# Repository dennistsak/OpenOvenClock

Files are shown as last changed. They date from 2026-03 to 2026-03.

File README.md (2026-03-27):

<p align="center">
  
</p>

# OpenOvenClock
An open-source oven timer project - and my first custom PCB design.

## Quick background
My oven's timer suddenly broke completely, producing an annoying loud noise whenever power was applied. After a teardown and some failed repair attempts on its badly worn PCB, it became clear that fixing it was not practical. Instead, I used this as an opportunity to design and manufacture my own PCB, adding some quality-of-life upgrades to the original timer design.

## Features & improvements
The new timer supports most of the original features including:
- 24-hour format time display.
- Time set screen with improved flow, in the form of button confirmation, instead of time based advance from hours to minutes.
- Countdown baking timer.

As well as several additions to the original design. More specifically:

- Rotary encoder with integrated switch. Supports single, double and long press inputs.
- Eco (night) mode. When enabled the display dims during the night.
- Configurable display brightness.
- Setting to disable optional buzzer sounds.
- Automatic locking after specific time.
- User friendly animations, that improve usability.
- Watchdog implementation in case of malfunction, defaulting in locked mode (disabled oven) after reset.
- Settings menu.
- Easily accessible reset button, with integrated hidden serial interface.

Some of this functionality can be seen below:

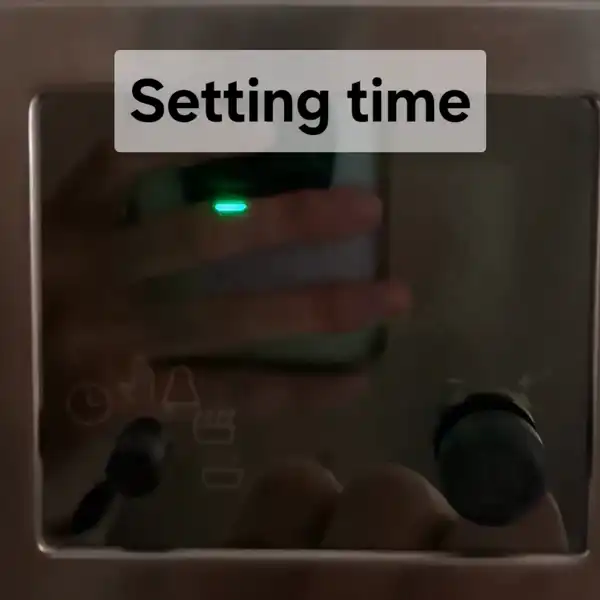
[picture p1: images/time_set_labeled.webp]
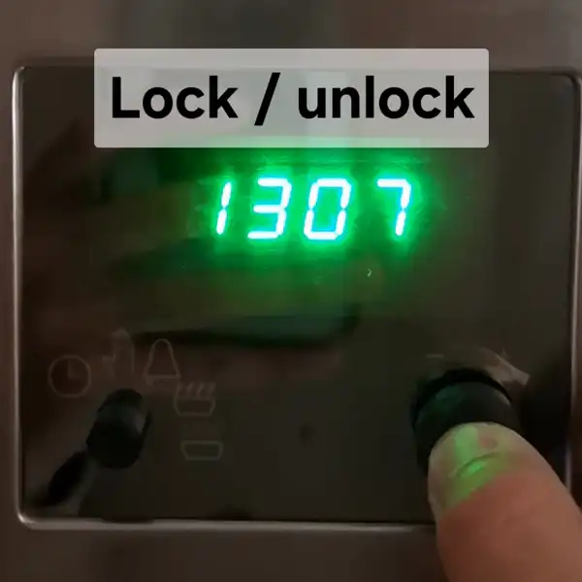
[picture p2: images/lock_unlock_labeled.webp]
|
:-------------------------------:|:-------------------------:
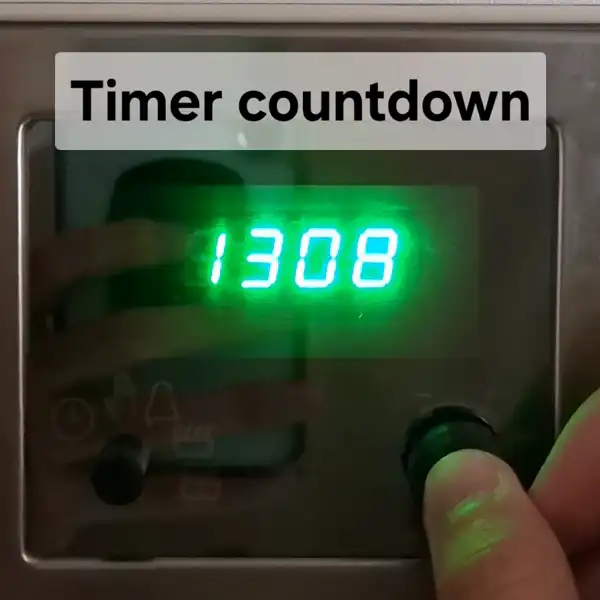
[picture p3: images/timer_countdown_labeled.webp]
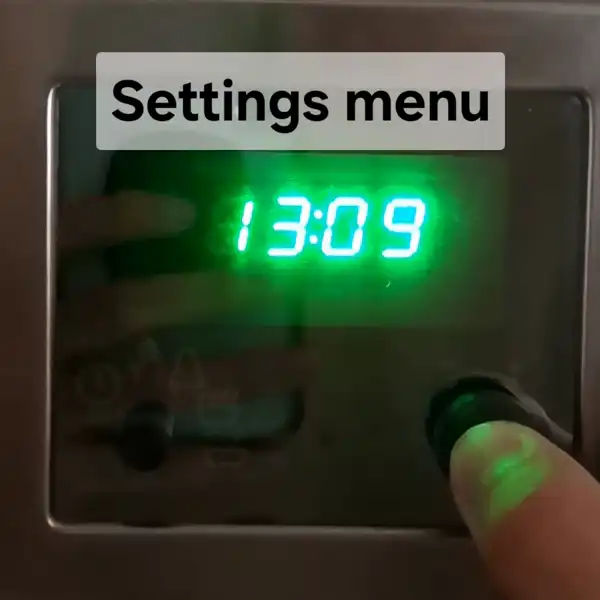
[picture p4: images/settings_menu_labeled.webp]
|

## Installation guide
In order to compile the firmware sketch for the ATmega328P, the Arduino IDE is required, as well as some 3rd party libraries.
### Libraries used:
- [LedControl](https://github.com/wayoda/LedControl) for communicating with the MAX7219.
- [DS3231](https://github.com/NorthernWidget/DS3231) for interfacing with the DS3231 RTC.
- [Switch](https://github.com/avdwebLibraries/avdweb_Switch) for rotary switch button de-bounce and multiple input type distinction.
- (Pre-installed) [Wire](https://docs.arduino.cc/language-reference/en/functions/communication/wire/) for I2C communication.
- (Pre-installed) [EEPROM](https://docs.arduino.cc/learn/built-in-libraries/eeprom/) for saving settings to the ATmega's EEPROM.
- (Pre-installed) [avr/wdt.h]() for implementing the watchdog timer.

After compiling the firmware sketch we need to flash it to the ATmega328P. For this guide we assume the use of the <b>FTDI FT232RL USB-to-Serial adapter</b>. In order for this adapter to function properly, it is required that the correct drivers are installed. This installation process is explained in great detail in this [guide](https://support.arduino.cc/hc/en-us/articles/4411305694610-Install-or-update-FTDI-drivers).

The final requirement for uploading the firmware, is an ATmega328P chip, that has a bootloader configured for using an external 16Mhz crystal, already burned. If such chip is unavailable, burning a bootloader is a relatively easy process by following the steps described in this [guide](https://support.arduino.cc/hc/en-us/articles/4841602539164-Burn-the-bootloader-on-UNO-Mega-and-classic-Nano-using-another-Arduino).

At this point, we are ready to proceed with the firmware flashing process. This process is described in the following steps:

1. Connect the USB-to-Serial adapter to the OpenOvenTimer board's serial port header.
2. Connect the USB-to-Serial adapter to an available USB port on the machine where Arduino IDE is installed.
3. Select the appropriate serial communication port inside Arduino IDE, when it appears.
4. Ensure the Serial Monitor window is closed, as it will in many cases interfere with the upload process.
5. Click the upload button and wait for the firmware flash process to complete.
6. Finally, click the reset button to get the micro-controller running on the new firmware.

## PCB design summary
During the PCB design process, several key challenges arose, the most important being the selection of devices that could reliably work together, to implement the desired functionality.

Some of the these choices are outlined below:

- When searching for a suitable micro-controller IC, the <b>ATmega328P-PN</b> variant was chosen, which provides slightly higher operating temperature margin, than the PU.
- For keeping track of time, the <b>DS3231 RTC</b> was selected. This IC provides more than adequate timekeeping functionality for this application, with an accuracy of ±3.5ppm until +85°C.
- A 4-digit 7-segment display is used, driven by a <b>MAX7219</b> IC. This display was selected as it was specifically made to support time format and the segments are green LEDs, that beautifully match the look of the original timer's VFD display.
- In order to include the auto baking functionality, a relay was added to switch the oven's loads (heaters, fan motors, etc). The selection process of an appropriate relay was tricky, as an oven consumes a lot of power. The original PCB used a relay that included quick-connect contacts. This eliminated the requirement for PCB traces that can handle large current.
<br>Taking these parameters into account, the <b>OMRON G4A-1A-E-DC5</b> relay was chosen. It provides a slightly higher contact current rating, while keeping the required coil voltage at 5V (instead of the original relay's 28V).
- For supplying power, a 5V PCB PSU module was selected, to save space and reduce complexity.

Board front side           |  Board back side
:-------------------------:|:-------------------------:
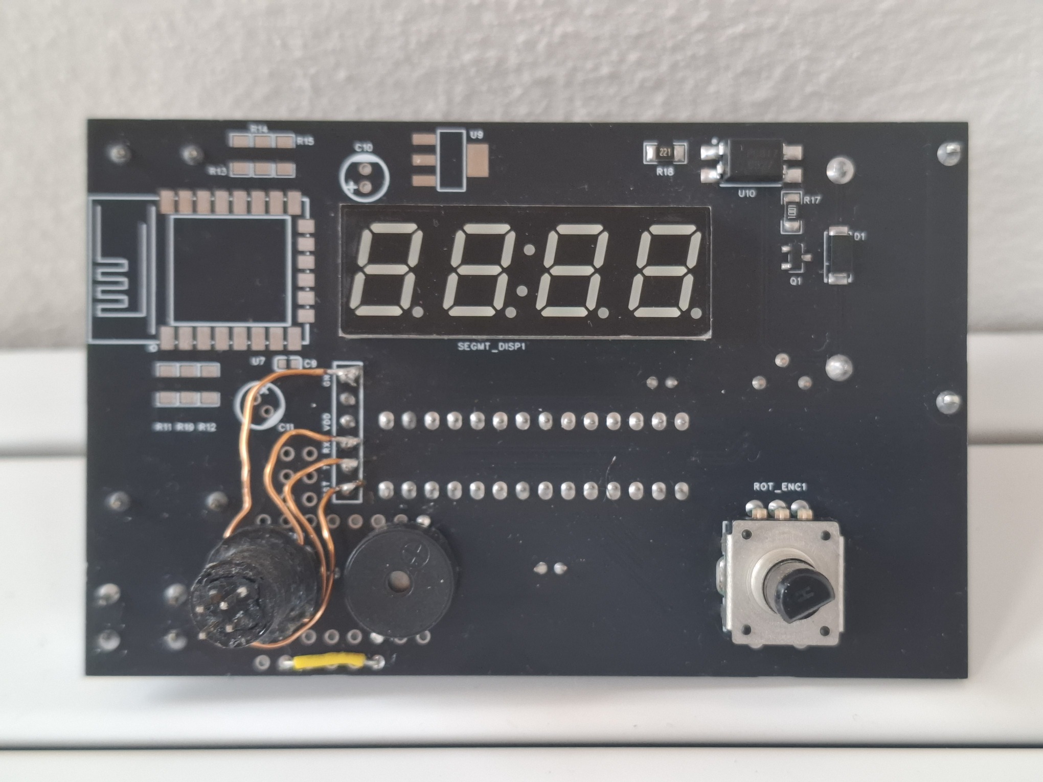
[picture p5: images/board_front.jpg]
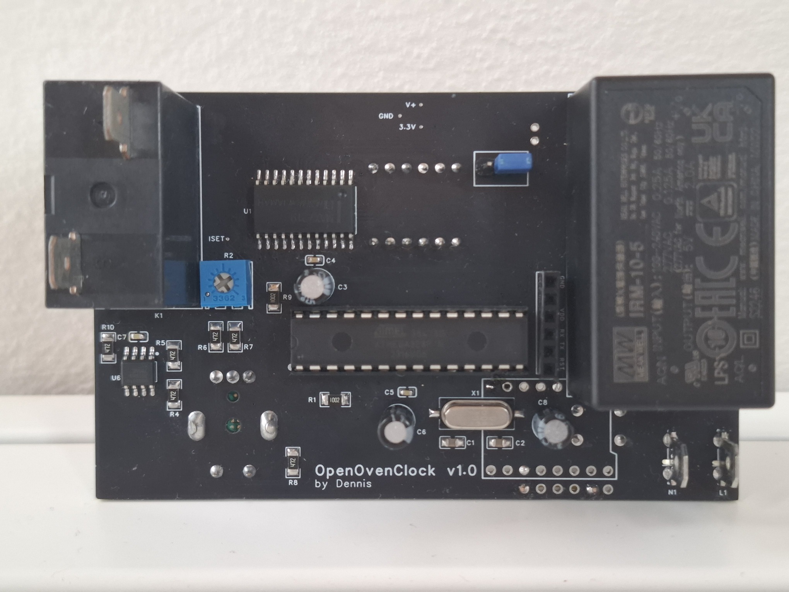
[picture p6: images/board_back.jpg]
|

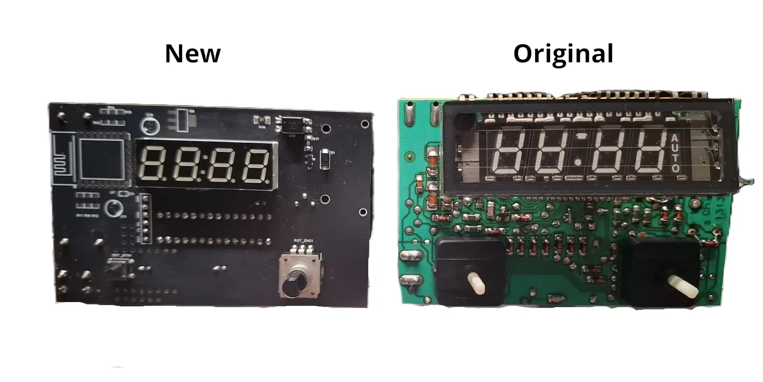
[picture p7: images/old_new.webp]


## Firmware design
While developing the firmware, a state machine architecture was used to ensure determinism.

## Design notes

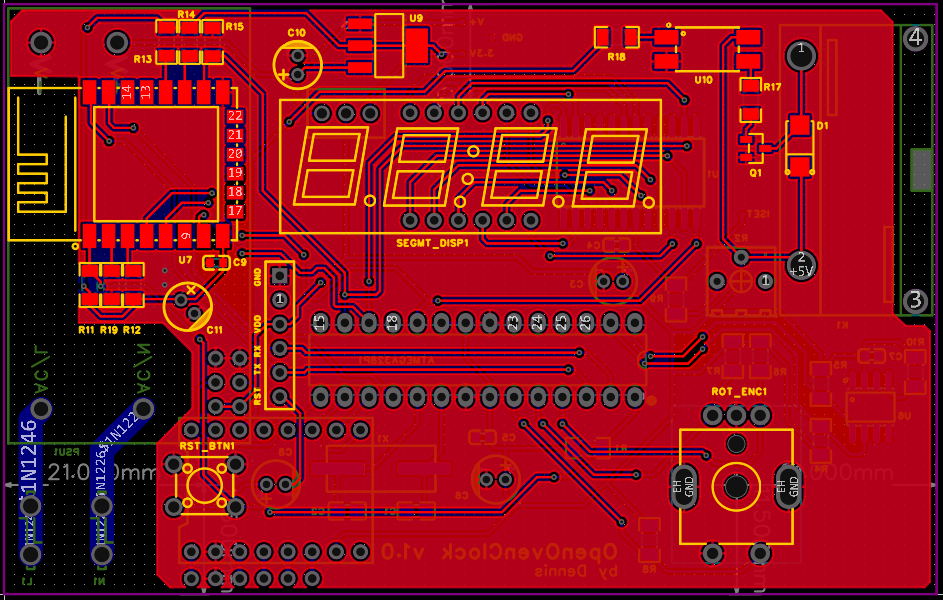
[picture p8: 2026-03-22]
images/pcb_eda.png

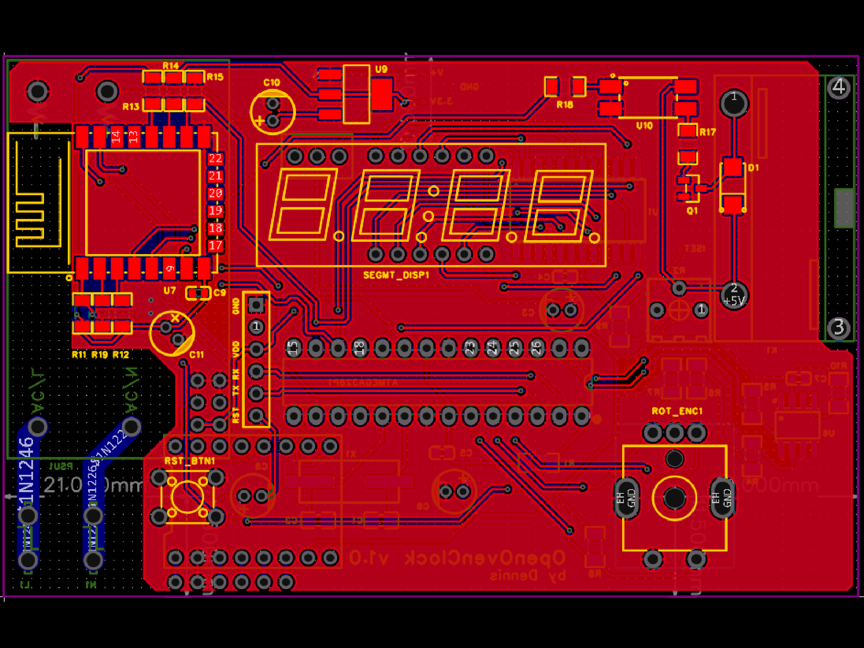
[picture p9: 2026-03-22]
images/pcb_eda_scaled.png

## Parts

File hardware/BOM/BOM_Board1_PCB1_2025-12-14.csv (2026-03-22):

No. | Quantity | Comment | Footprint | Value | Manufacturer Part | Manufacturer | Supplier Part | Supplier | Unique ID | LCSC Part Name | Designator
1 | 1 | 1kΩ | R1206 | 1kΩ | 1206W4F1001T5E | UNI-ROYAL(厚声) | C4410 | LCSC | gge25 | 1kΩ ±1% 250mW 厚膜电阻 | R17
2 | 1 | 2AS4T1A1M2RES | SW-TH_3P-P2.54_2AS4T1A1M2RES |  | 2AS4T1A1M2RES | HOOYA(皓宇电子) | C20611706 | LCSC | gge35 | 摇摆开关 | U12
3 | 1 | 2.4GHz | WIFIM-SMD_ESP-12F-ESP8266MOD | 2.4GHz | ESP-12F(ESP8266MOD) | Ai-Thinker(安信可) | C82891 | LCSC | gge21 | 完整的802.11b/g/nWi-FiSoC模块 屏蔽罩上的丝印是：ESP8266MOD，ESP8266EX串口WIFI | U7
4 | 1 | 16MHz | HC-49S_L11.4-W4.8 | 16MHz | X49SM16MSD2SC | YXC(扬兴晶振) | C12676 | LCSC | gge9 | HC-49SMD 16MHZ 2P 49SMD 20PF ±20PPM -20~70℃（±30PPM） | X1
5 | 1 | 50kΩ | RES-ADJ-TH_3362P | 50kΩ | 3362P-1-503 | JIERR(捷而瑞) | C48997904 | LCSC | gge14 | 3362P-1-503 | R2
6 | 1 | 220Ω | R1206 | 220Ω | 1206W4J0221T5E | UNI-ROYAL(厚声) | C25363 | LCSC | gge34 | 220Ω ±5% 250mW 厚膜电阻 | R18
7 | 1 | AMS1117-3.3 | SOT-223-3_L6.4-W3.5-P2.30-LS7.0-BR |  | AMS1117-3.3 | 国芯佳品 | C2992570 | LCSC | gge22 | 1A低压差线性稳压器 | U9
8 | 1 | ATMEGA328P-PN | PDIP-28_L35.0-W7.3-P2.54-LS7.8-BL |  | ATMEGA328P-PN | MICROCHIP(美国微芯) | C1337455 | LCSC | gge6 | 基于AVR增强型RISC架构的低功耗CMOS 8位微控制器 | ATMEGA328P1
9 | 1 | DS3231MZ+TRL | SOIC-8_L4.9-W3.9-P1.27-LS6.0-BL |  | DS3231MZ+TRL | ADI(亚德诺)/MAXIM(美信) | C107410 | LCSC | gge17 | 高精度RTC集成MEMS谐振器 | U6
10 | 1 | EC11G1560421 | SW-TH_EC11G1560421 |  | EC11G1560421 | ALPSALPINE(阿尔卑斯阿尔派) | C1322549 | LCSC | gge11 | 编码器 | ROT_ENC1
11 | 1 | G4A-1A-E DC12 | RELAY-TH_G4A-1A-E |  | G4A-1A-E DC12 | OMRON(欧姆龙) | C1563460 | LCSC | gge20 | 无锁存 | K1
12 | 1 | IRM-05-5 | PWRM-TH_IRM-05-5 |  | IRM-05-5 | null | C48603696 | LCSC | gge2 | MW(明纬) 单输出封装型PCB安装型胶囊型绿色模块开关电源 AC-DC 5W IRM-05-5 | PSU1
13 | 1 | M7 | SMA_L4.3-W2.6-LS5.2-RD |  | M7 | MDD(辰达半导体) | C95872 | LCSC | gge26 | 1kV 1A | D1
14 | 1 | MAX7219M/TR | SOP-24_L15.4-W7.5-P1.27-LS10.4-BL |  | MAX7219M/TR | HGSEMI(华冠) | C6705351 | LCSC | gge1 | MAX7219M/TR | U1
15 | 1 | PC817C | OPTO-SMD-4_L4.6-W6.5-P2.54-LS10.3-TL |  | PC817C | GOODWORK(固得沃克) | C3025164 | LCSC | gge24 | C档 光电晶体管光电耦合器 | U10
16 | 1 | SLR0394FG3C5BD-3.5 | LED-SEG-TH_SLR0394FG3C5BD-3.5 |  | SLR0394FG3C5BD-3.5 | SUNLIGHT(光华) | C225905 | LCSC | gge3 | 4位0.39英寸绿色数码管 共阴极 | SEGMT_DISP1
17 | 1 | SS8050(RANGE:200-350) | SOT-23-3_L2.9-W1.3-P1.90-LS2.4-BR |  | SS8050(RANGE:200-350) | CJ(江苏长电/长晶) | C2150 | LCSC | gge27 | hfe=200~350 NPN 电流:1.5A 电压:25V | Q1
18 | 1 | TS-1002-07026 | SW-TH_4P-L6.0-W6.0-P4.50-LS6.5 |  | TS-1002-07026 | XUNPU(讯普) | C455095 | LCSC | gge16 | 6*6*7mm 直插 轻触开关 | RST_BTN1
19 | 2 | 22pF | C0805 | 22pF | TCC0805COG220J500BT | CCTC(三环) | C376875 | LCSC | gge7,gge8 | 22pF ±5% 50V | C1,C2
20 | 2 | G630-09-3T | CONN-TH_2P-L8.2-W0.8-P5.10 |  | G630-09-3T | SAMZO(三佐) | C27636945 | LCSC | gge4,gge5 | 6.3mmPCB焊接端子-插片 | L1,N1
21 | 4 | 100nF | C0603 | 100nF | CL10B104KB8NNNC | SAMSUNG(三星) | C1591 | LCSC | gge12,gge12_1,gge12_2,gge12_3 | 100nF ±10% 50V | C3,C5,C7,C9
22 | 4 | Test-Point | Test-Point-0.5mm |  |  |  |  |  | gge28,gge29,gge30,gge33 |  | 3.3V,GND,ISET,V+
23 | 5 | 10uF | CAP-TH_BD5.0-P2.00-D0.8-FD | 10uF | 50YXJ10M5X11 | Rubycon(红宝石) | C432355 | LCSC | gge13,gge13_1,gge13_2,gge13_3,gge13_4 | 10uF ±20% 50V | C4,C6,C8,C10,C11
24 | 6 | 4.7kΩ | R1206 | 4.7kΩ | FRC1206J472 TS | FOJAN(富捷) | C2907499 | LCSC | gge18,gge18_1,gge18_2,gge18_3,gge19,gge19_1 | 4.7kΩ ±5% 250mW 厚膜电阻 | R4,R5,R6,R7,R8,R10
25 | 8 | 10kΩ | R1206 | 10kΩ | 1206W4F1002T5E | UNI-ROYAL(厚声) | C17902 | LCSC | gge10,gge10_1,gge10_2,gge10_3,gge10_4,gge10_5,gge10_6,gge10_7 | 10kΩ ±1% 250mW 厚膜电阻 | R1,R9,R11,R12,R13,R14,R15,R19

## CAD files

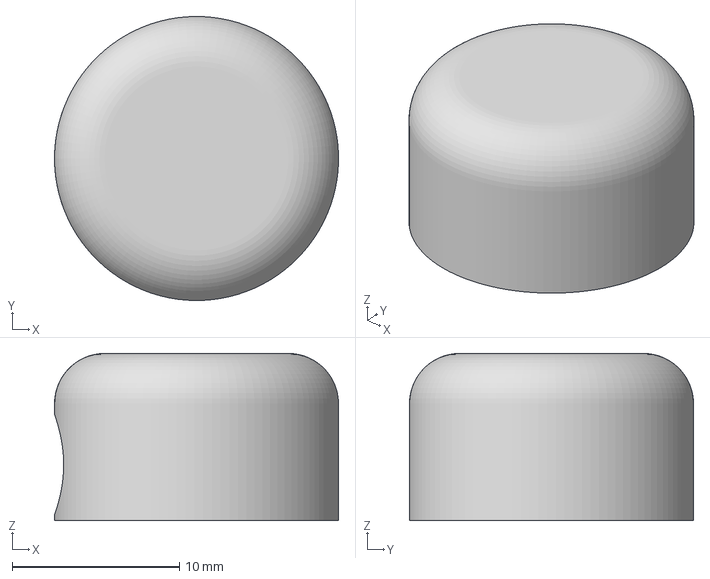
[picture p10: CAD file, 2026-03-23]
hardware/3D_models/knob_cap_v4.3mf
17.0 x 17.0 x 10.0 mm

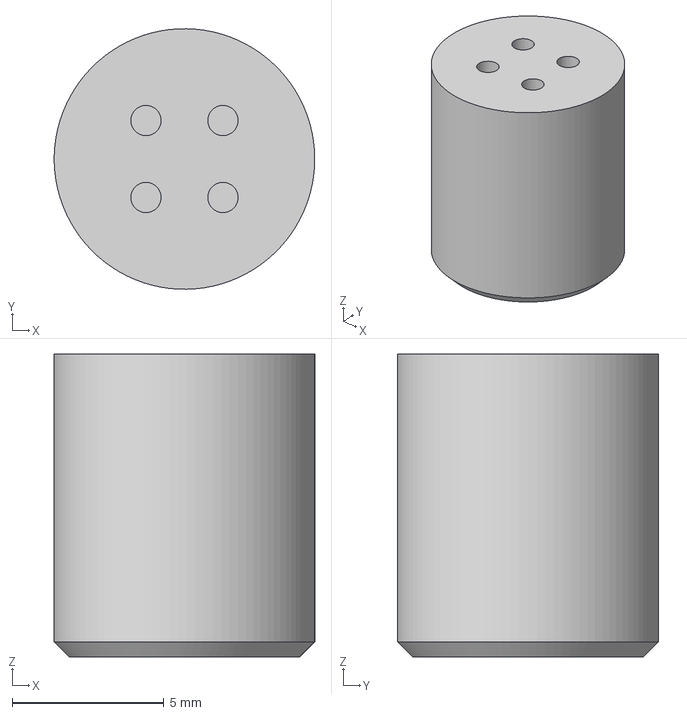
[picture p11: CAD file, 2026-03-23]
hardware/3D_models/rst_button_cap.3mf
8.60 x 8.60 x 10.0 mm

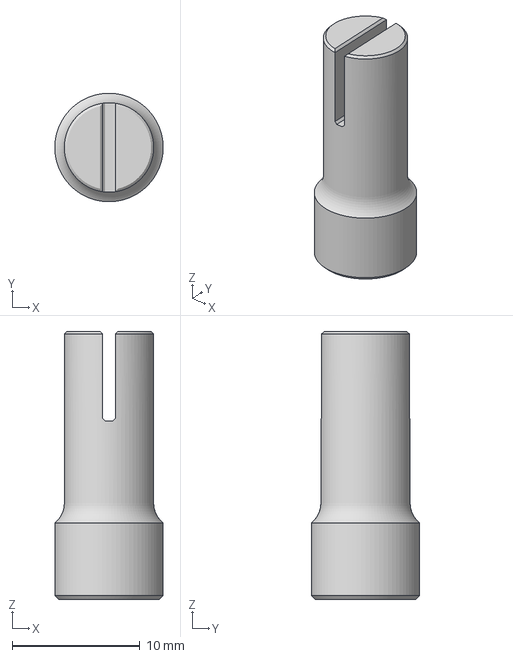
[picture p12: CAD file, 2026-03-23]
hardware/3D_models/knob_adapter_v4.3mf
8.50 x 8.49 x 21.0 mm

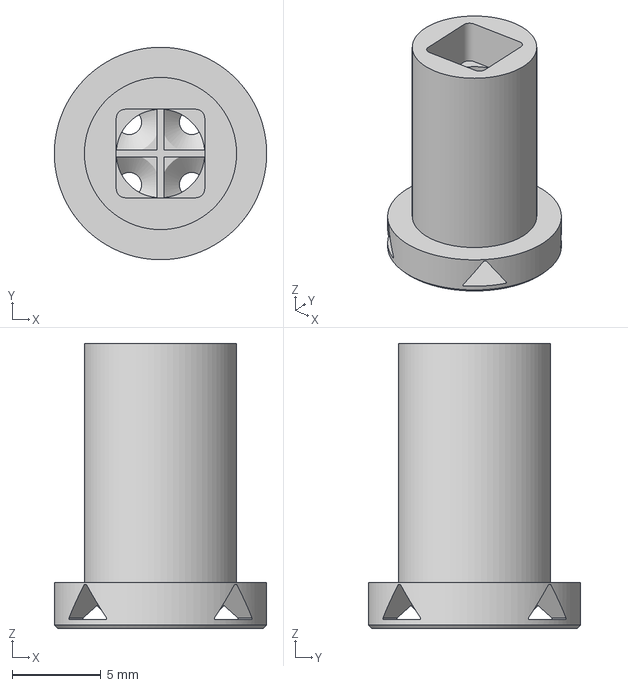
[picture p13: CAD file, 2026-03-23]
hardware/3D_models/rst_button.3mf
12.0 x 12.0 x 16.1 mm

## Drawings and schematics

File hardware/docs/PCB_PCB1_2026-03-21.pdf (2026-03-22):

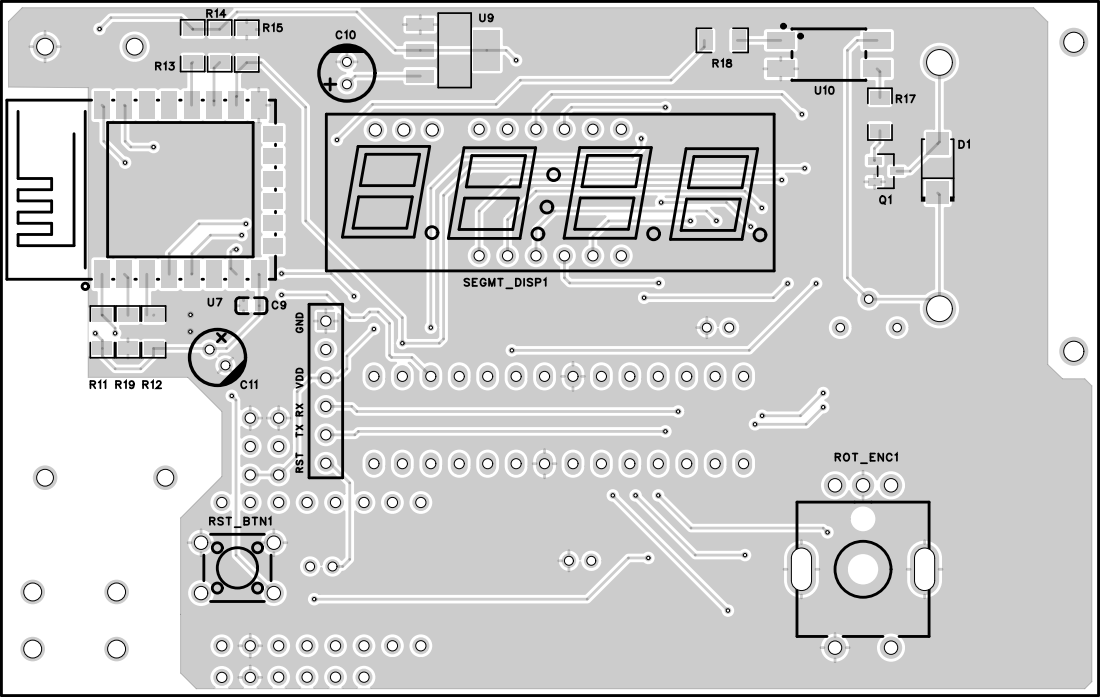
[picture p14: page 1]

RST TX RX VDD GND

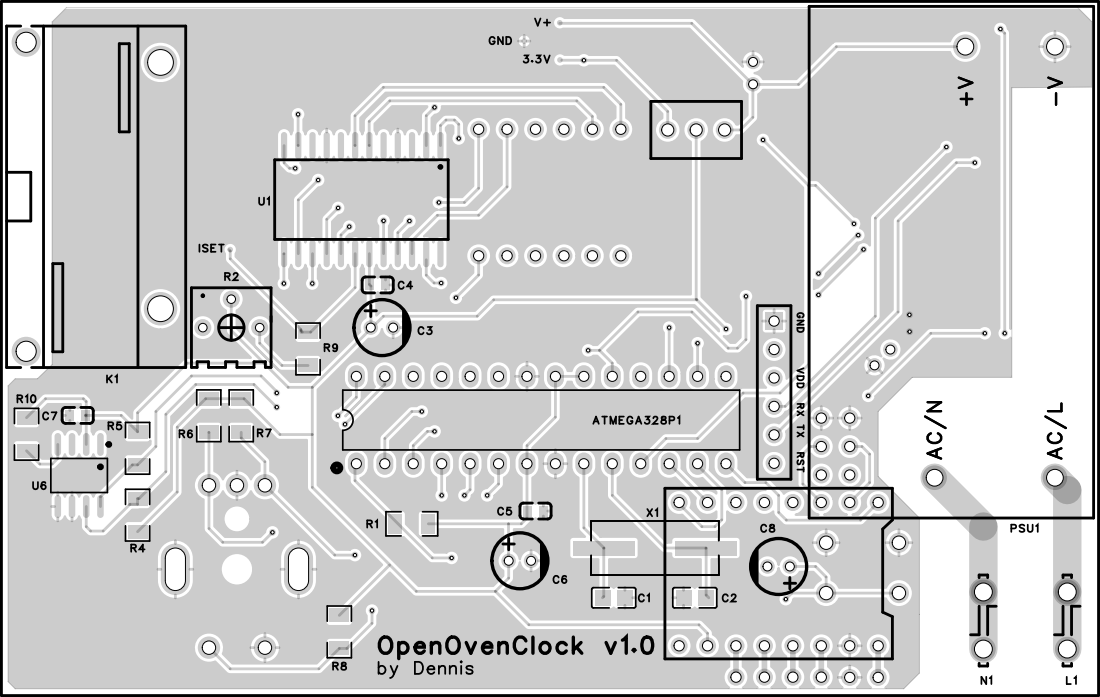
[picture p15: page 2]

GND VDD RX TX RST

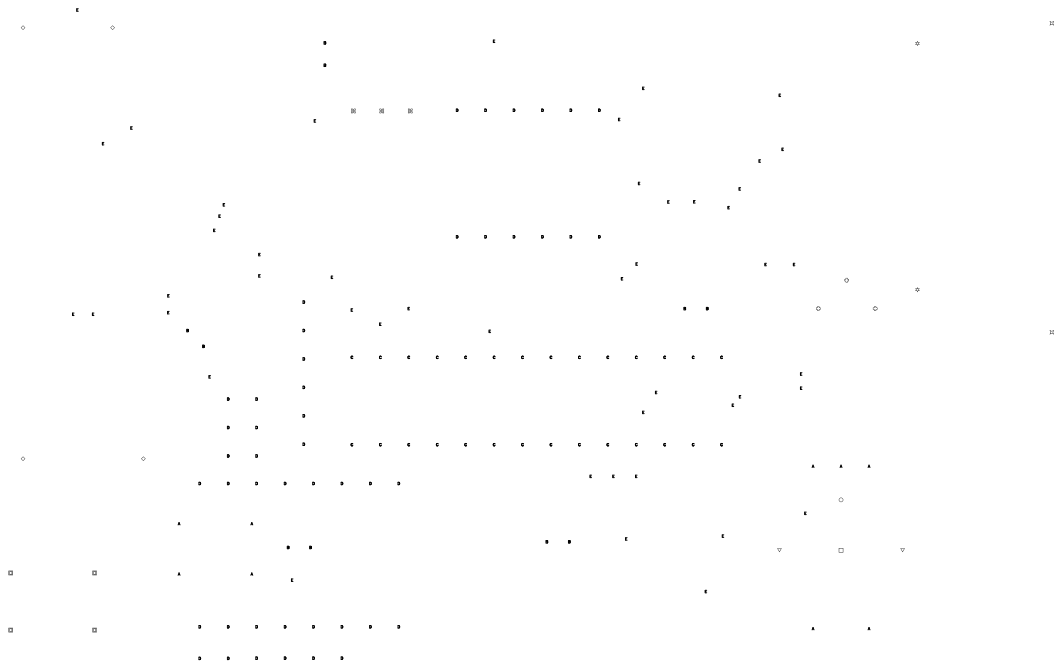
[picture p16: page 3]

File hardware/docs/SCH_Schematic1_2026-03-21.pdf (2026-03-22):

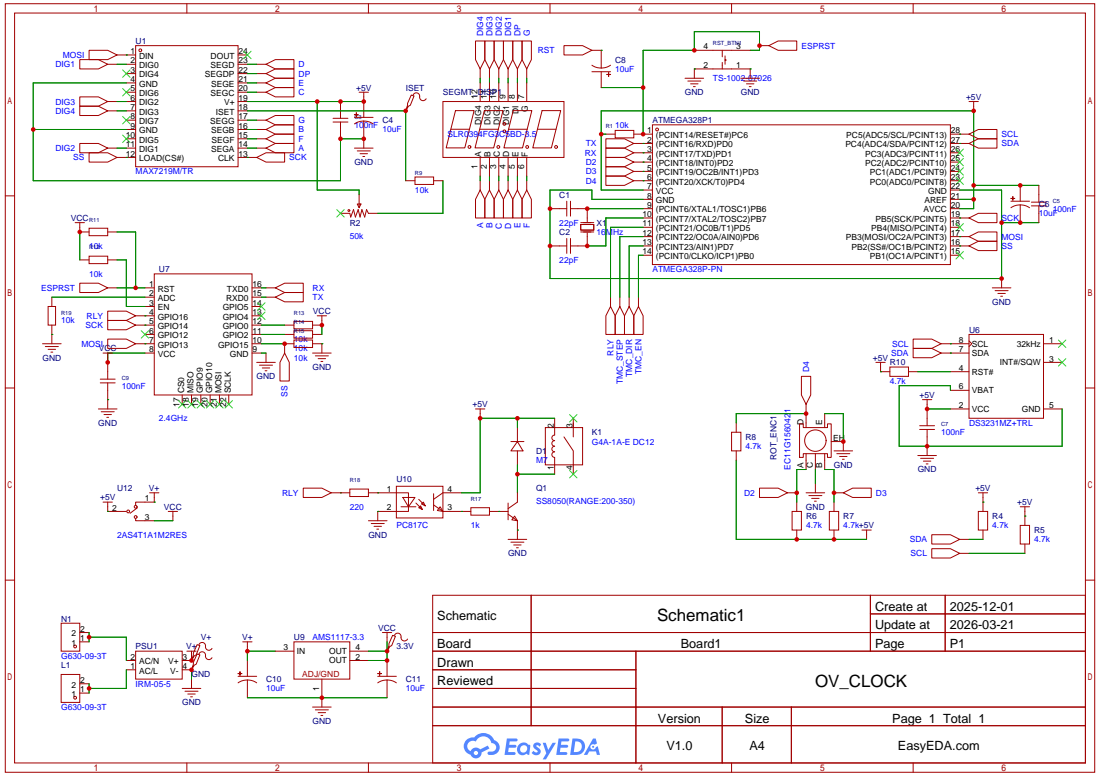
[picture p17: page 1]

Schematic | Schematic1 | Create at | 2025-12-01

Update at | 2026-03-21

Board | Board1 | Page | P1
Drawn | | OV_CLOCK
Reviewed

Version | Size | Page 1 Total 1
V1.0 | A4 | EasyEDA.com

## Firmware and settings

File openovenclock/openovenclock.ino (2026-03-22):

#include <LedControl.h>
#include <DS3231.h>
#include <Switch.h>
#include <Wire.h>
#include <EEPROM.h>
#include <avr/wdt.h>

#define SS_PIN 10
#define MOSI_PIN 11
#define SCK_PIN 13

#define ENCODER_MASK 0b00001100


/* 7-Segment Display */
LedControl lc = LedControl(MOSI_PIN, SCK_PIN, SS_PIN, 1);

unsigned long delaytime = 500;

int load_anim_rows[] = {0,1,2,3,3,3,3,2,1,0,0,0};
int load_anim_col[] = {1,1,1,1,2,3,4,4,4,4,5,6};
void settingLabel(int);
void settingValue(int);
uint32_t getTimeSec(byte, byte, byte);
bool timePassed(uint32_t, uint32_t);
void beep();
void doubleBeep();
void beepError();
void alertShort();
void alertLong();
void lockOven();
void unlockOven();
void factoryReset();

/* Real Time Clock */
DS3231 rtc;
bool h12Flag;
bool pmFlag;
byte HOUR, MINUTE, SECOND, TIMER_H, TIMER_M, TIMER_S;
uint32_t targetSec;
uint32_t nowSec;
uint32_t remaining;

/* Rotary encoder */
int pinA = 2;
int pinB = 3;
volatile byte flag1 = 0;
volatile byte flag2 = 0;
volatile byte encPosition = 0;
volatile byte oldEncPos = 0;
volatile byte regVals = 0;
volatile unsigned long debounce = 200;
volatile unsigned long long_press = 3000;
Switch encButton = Switch(4, INPUT, false, 50, 2500, 250, 10);

/* Relay */
int relayPin = 5;
volatile bool heaterOn = false;

/* Buzzer */
int buzzerPin = 7;

/* FSM variables */
unsigned int edit_time_state = 0;
unsigned long edit_time_stamp = 0;
bool edit_time_vis = true;

unsigned long refresh_delay = 0;
bool disp_time_vis = true;
unsigned long anim_d = 0;
unsigned int anim_i = 0;
unsigned long anim_j = 0;
unsigned long ovenUnlockMillis = 0;
const unsigned long ovenMaxUnlockTime = 10UL * 60UL * 60UL * 1000UL; // 10h
const unsigned long ecoStartTime = 20UL * 3600;
const unsigned long ecoStopTime = 6UL * 3600;
// const unsigned long ovenMaxUnlockTime = 10000UL; // 10s
bool locked = true;

/* settings variables */
int setting_i = 0;
bool edit_setting = false;
byte brightness = 1;
bool eco_mode = false;
bool silent_mode = false;

/* EEPROM addresses */
#define E_INIT     10 /* initialization check address */
#define BRIGHTNESS 0
#define ECO        1
#define SILENT     2

unsigned int state = 0;

void setup() {
  /* IMPORTANT! DO NOT CHANGE! */
  pinMode(SS_PIN, OUTPUT);  // PB2 / SS must be OUTPUT
  digitalWrite(SS_PIN, HIGH);
  /*---------------------------*/

  /* Enable watchdog timer */
  wdt_enable(WDTO_8S);

  /* Setup relay pin */
  pinMode(relayPin, OUTPUT);
  heaterOn = false;

  /* Setup buzzer pin */
  pinMode(buzzerPin, OUTPUT);

  /* Start serial */
  Serial.begin(9600);

  /* Check EEPROM state */
  if (EEPROM.read(E_INIT) != 'I') {
    Serial.println("EEPROM not initialized!");
    EEPROM.write(BRIGHTNESS, brightness);
    EEPROM.write(ECO, eco_mode);
    EEPROM.write(SILENT, silent_mode);
    EEPROM.write(E_INIT, 'I');
    Serial.println("EEPROM initialized Successfully!");
  }

  /* Load settings from EEPROM */
  brightness = EEPROM.read(BRIGHTNESS);
  eco_mode = EEPROM.read(ECO);
  silent_mode = EEPROM.read(SILENT);
  Serial.println("-------- Settings --------");
  Serial.print("Brighness: ");
  Serial.println(brightness, DEC);
  Serial.print("Eco: ");
  Serial.println(eco_mode);
  Serial.print("Silent: ");
  Serial.println(silent_mode);
  Serial.println("--------------------------");

  /* 7-Segment display test animation */
  lc.shutdown(0, false);
  lc.setIntensity(0, 1);
  lc.clearDisplay(0);
  for (int i=0; i<12; i++) {
    lc.clearDisplay(0);
    lc.setLed(0, load_anim_rows[i], load_anim_col[i], true);
    if (!silent_mode) {
      tone(buzzerPin, 8000);
    }
    delay(25);
    noTone(buzzerPin);
    delay(25);
  }
  lc.clearDisplay(0);

  /* Start I2C communication for RTC */
  Wire.begin();

  /* Initial FSM state */
  state = 0;
  edit_time_state = 0;

  /* Encoder pin interrupt initialization */
  pinMode(pinA, INPUT_PULLUP);
  pinMode(pinB, INPUT_PULLUP);
  attachInterrupt(digitalPinToInterrupt(pinA), pinARoutine, RISING);
  attachInterrupt(digitalPinToInterrupt(pinB), pinBRoutine, RISING);

  beep();
}


int value1 = 0;
int value2 = 0;


void pinARoutine(){
  regVals = PIND & ENCODER_MASK;
  if (regVals == B00001100 && flag1) {
    flag2 = 0;
    flag1 = 0;
    encPosition--;
  } else if (regVals == B00000100) {
    flag2 = 1;
  }
}

void pinBRoutine(){
  regVals = PIND & ENCODER_MASK;
  if (regVals == 0b00001100 && flag2) {
    flag2 = 0;
    flag1 = 0;
    encPosition++;
  } else if (regVals == 0b00001000) {
    flag1 = 1;
  }
}

void loop() {
  /* Feed the watchdog. */
  wdt_reset();

  /* Update heater relay logic */
  if (heaterOn && !locked) {
    digitalWrite(relayPin, HIGH);
  } else {
    digitalWrite(relayPin, LOW);
  }

  /* Lock oven automatically if it's been 10h */
  if (millis() - ovenUnlockMillis > ovenMaxUnlockTime && !locked) {
    lockOven();
  }

  /* FSM */
  switch(state)
  {
    case 0: // ---------- SET TIME -------------
    {
      if (millis() - edit_time_stamp > 300) { 
        edit_time_vis = !edit_time_vis;
        edit_time_stamp = millis();

        if (edit_time_state == 0)
        {
          lc.clearDisplay(0);
          lc.setIntensity(0, brightness);
          if (edit_time_vis) {
            lc.setDigit(0, 0, HOUR/10, false);
            lc.setDigit(0, 1, HOUR%10, false);
          }
          lc.setDigit(0, 2, MINUTE/10, false);
          lc.setDigit(0, 3, MINUTE%10, false);
        } 
        if (edit_time_state == 1)
        {
          lc.clearDisplay(0);
          lc.setIntensity(0, brightness);
          lc.setDigit(0, 0, HOUR/10, false);
          lc.setDigit(0, 1, HOUR%10, false);
          if (edit_time_vis) {
            lc.setDigit(0, 2, MINUTE/10, false);
            lc.setDigit(0, 3, MINUTE%10, false);
          }
        }
        lc.setLed(0, 1, 0, true);
        lc.setLed(0, 3, 0, true);
      }
      break;
    }
    case 1: // ---------- DISPLAY TIME ----------
    {
      if (millis() - refresh_delay > 1000) {
        disp_time_vis = !disp_time_vis;
        refresh_delay = millis();
        byte hour = rtc.getHour(h12Flag, pmFlag);
        byte min = rtc.getMinute();
        byte dig01, dig23;

        dig01 = hour;
        dig23 = min;

        lc.clearDisplay(0);
        
        /* Eco mode brightness logic */
        if (eco_mode) {
          nowSec = getTimeSec(hour, min, 0); /* Get currect seconds with only hour and minute accuracy. */
          if (nowSec >= ecoStartTime || nowSec < ecoStopTime) {
            lc.setIntensity(0, 0);
          } else {
            lc.setIntensity(0, brightness);
          }
        } else {
          lc.setIntensity(0, brightness);
        }

        if (dig01 > 9) {
          lc.setDigit(0, 0, dig01/10, false);
        }
        lc.setDigit(0, 1, dig01%10, false);
        lc.setDigit(0, 2, dig23/10, false);
        lc.setDigit(0, 3, dig23%10, false);
        if (disp_time_vis) {
          lc.setLed(0, 1, 0, true);
          lc.setLed(0, 3, 0, true);
        }

        if (!locked) {
          heaterOn = true;
        } else {
          heaterOn = false;
        }
      }
      break;
    }
    case 2: // ---------- SET TIMER SCREEN ----------
    {
      if (millis() - edit_time_stamp > 300) { 
        edit_time_vis = !edit_time_vis;
        edit_time_stamp = millis();

        if (edit_time_state == 0)
        {
          lc.clearDisplay(0);
          lc.setIntensity(0, brightness);
          if (edit_time_vis) {
            byte h0 = TIMER_H/10;
            byte h1 = TIMER_H%10;
            if (h0 != 0) { lc.setDigit(0, 0, h0, false); }
            if (h1 != 0) { lc.setDigit(0, 1, h1, false); }
          } else {
            lc.setLed(0, 0, 7, true);
            lc.setLed(0, 1, 7, true);
          }
          lc.setDigit(0, 2, TIMER_M/10, false);
          lc.setDigit(0, 3, TIMER_M%10, false);
        } 
        if (edit_time_state == 1)
        {
          lc.clearDisplay(0);
          lc.setIntensity(0, brightness);
          lc.setDigit(0, 0, TIMER_H/10, false);
          lc.setDigit(0, 1, TIMER_H%10, false);
          if (edit_time_vis) {
            byte m0 = TIMER_M/10;
            byte m1 = TIMER_M%10;
            lc.setDigit(0, 2, m0, false);
            lc.setDigit(0, 3, m1, false);
          } else {
            lc.setLed(0, 2, 7, true);
            lc.setLed(0, 3, 7, true);
          }
        }
        lc.setLed(0, 1, 0, true);
        lc.setLed(0, 3, 0, true);
      }
      break;
    }
    case 3: // ---------- TIMER COUNTDOWN ----------
    {
      if (timePassed(nowSec, targetSec)) {
        state = 5;
        alertLong();
      }
      if (millis() - refresh_delay > 1000) {
        refresh_delay = millis();

        // Get remaining seconds
        byte nowHour = rtc.getHour(h12Flag, pmFlag);
        byte nowMinute = rtc.getMinute();
        byte nowSecond = rtc.getSecond();
        nowSec = getTimeSec(nowHour, nowMinute, nowSecond);
        remaining = (targetSec + 86400UL - nowSec) % 86400UL;
        byte hour = remaining / 3600;
        byte min = (remaining % 3600) / 60;
        byte sec = remaining % 60;
        byte dig01, dig23;

        if (remaining < 3600) {
          dig01 = min;
          dig23 = sec;
        } else {
          dig01 = hour;
          dig23 = min;
        }

        lc.clearDisplay(0);
        lc.setIntensity(0, brightness);
        if (dig01 > 9) {
          lc.setDigit(0, 0, dig01/10, false);
        }
        lc.setDigit(0, 1, dig01%10, false);
        lc.setDigit(0, 2, dig23/10, false);
        lc.setDigit(0, 3, dig23%10, false);
        lc.setLed(0, 1, 0, true);
        lc.setLed(0, 3, 0, true);
      }
      if (millis() - anim_d > 50 && disp_time_vis) {
        if (remaining > 3600 || remaining < 600) {
          anim_d = millis();
          anim_i++;
          if(anim_i > 6) { anim_i = 1; }
          for (int i=0; i<7; i++) {
            lc.setLed(0, 0, i, false);
          }
          lc.setLed(0, 0, anim_i, true);
        }
      }
      break;
    }
    case 4: // ---------- SETTINGS MENU ----------
    {
      if (millis() - edit_time_stamp > 200) {
        edit_time_vis = !edit_time_vis;
        edit_time_stamp = millis();
        lc.clearDisplay(0);
        lc.setIntensity(0, brightness);
        settingLabel(setting_i);
        if (!edit_setting) {
          settingValue(setting_i); 
        } else { 
          if (edit_time_vis) {
            settingValue(setting_i);
          }
        }
      }
      break;
    }
    case 5: // ---------- OVEN HALT --------------
    {
      if (millis() - refresh_delay > 50) {
        refresh_delay = millis();
        heaterOn = false;
        lc.clearDisplay(0);
        lc.setIntensity(0, brightness);
        lc.setChar(0, 0, 'e', false);
        lc.setChar(0, 1, 'n', false);
        lc.setChar(0, 2, 'd', false);
      }
      break;
    }
    default:
      Serial.println("Invalid FSM state (main).");
      break;
  }

  /* ----- Handle encoder position change ----- */
  if(oldEncPos != encPosition) {
    Serial.println(encPosition);
    int direction = 0;
    if (encPosition < oldEncPos || (encPosition == 255 && oldEncPos == 0)) { direction = 1; }
    if (encPosition == 0 && oldEncPos == 255) { direction = 0; }
    switch(state)
    {
      case 0: // ---------- SET TIME -------------
      {
        if (direction == 0)
        {
          if (edit_time_state == 0) {
            if (HOUR < 23) { HOUR++; }
            else { HOUR = 0; }
          }
          if (edit_time_state == 1) {
            if (MINUTE < 59) { MINUTE++; }
            else { MINUTE = 0; }
          }
        }
        else if (direction == 1)
        {
          if (edit_time_state == 0) {
            if (HOUR > 0) { HOUR--; }
            else { HOUR = 23; }
          }
          if (edit_time_state == 1) {
            if (MINUTE > 0) { MINUTE--; }
            else { MINUTE = 59; }
          }
        }
        beep();
        break;
      }
      case 1: // ---------- DISPLAY TIME ----------
      {
        beepError();
        if (locked) { showLockscreen(); }
        break;
      }
      case 2: // ---------- SET TIMER SCREEN ----------
      {
        if (direction == 0)
        {
          if (edit_time_state == 0) {
            if (TIMER_H < 9) { TIMER_H++; }
            //else { TIMER_H = 0; }
          }
          if (edit_time_state == 1) {
            if (TIMER_M < 59) { TIMER_M++; }
            else { TIMER_M = 0; }
          }
        }
        else if (direction == 1)
        {
          if (edit_time_state == 0) {
            if (TIMER_H > 0) { TIMER_H--; }
            //else { TIMER_H = 6; }
          }
          if (edit_time_state == 1) {
            if (TIMER_M > 0) { TIMER_M--; }
            else { TIMER_M = 59; }
          }
        }
        beep();
        break;
      }
      case 3: // ---------- TIMER COUNTDOWN ----------
      {
        beepError();
        break;
      }
      case 4: // ---------- SETTINGS MENU ----------
      {
        if (edit_setting)
        {
          switch(setting_i)
          {
            case 0:
            {
              if (direction == 0)
              {
                if (brightness < 15) { brightness++; }
              }
              else if (direction == 1)
              {
                if (brightness > 0) { brightness--; }
              }
              break;
            }
            case 1:
            {
              eco_mode = !eco_mode;
              break;
            }
            case 2:
            {
              silent_mode = !silent_mode;
              break;
            }
            case 3:
            {
              break;
            }
            default:
              break;
          }
        } else {
          if (direction == 0)
          {
            setting_i++;
            if (setting_i > 3) { setting_i = 0; }
          }
          else if (direction == 1)
          {
            setting_i--;
            if (setting_i < 0) { setting_i = 3; }
          }
        }
        beep();
        break;
      }
      case 5: // ---------- OVEN HALT --------------
      {
        state = 1;
        lockOven();
        beep();
        break;
      }
      default:
        Serial.println("Invalid FSM state (encoder turn).");
        break;
    }
    oldEncPos = encPosition;
  }

  encButton.poll();
  /* ----- Handle encoder button short press ----- */
  if (encButton.singleClick()) {
    Serial.println("Short press.");
    switch(state)
    {
      case 0: // ---------- SET TIME -------------
      {
        if (edit_time_state == 0) {
          edit_time_state = 1;
          rtc.setHour(HOUR);
        } else {
          rtc.setMinute(MINUTE);
          rtc.setSecond(0);
          edit_time_state = 0;
          state = 1;
        }
        beep();
        break;
      }
      case 1: // ---------- DISPLAY TIME ----------
      {
        if (locked) {
          beepError();
          showLockscreen();
          break;  
        }
        edit_time_state = 0;
        TIMER_H = 0;
        TIMER_M = 0;
        TIMER_S = 0;
        state = 2;
        beep();
        break;
      }
      case 2: // ---------- SET TIMER SCREEN ----------
      {
        if (edit_time_state == 0) {
          edit_time_state = 1;
        } else {
          edit_time_state = 0;

          // Calculate duration and start oven
          byte hour = rtc.getHour(h12Flag, pmFlag);
          byte minute = rtc.getMinute();
          byte second = rtc.getSecond();
          uint32_t nowSec = getTimeSec(hour, minute, second);
          uint32_t addSec = getTimeSec(TIMER_H, TIMER_M, 0);
          targetSec = (nowSec + addSec) % 86400UL;

          ovenUnlockMillis = millis();
          heaterOn = true;
          state = 3;
          alertShort();
        }
        beep();
        break;
      }
      case 3: // ---------- TIMER COUNTDOWN ----------
      {
        state = 5;
        beep();
        break;
      }
      case 4: // ---------- SETTINGS MENU ----------
      {
        edit_setting = !edit_setting;
        if (!edit_setting) {
          EEPROM.update(BRIGHTNESS, brightness);
          EEPROM.update(ECO, eco_mode);
          EEPROM.update(SILENT, silent_mode);
          doubleBeep();
        } else {
          beep();
        }
        break;
      }
      case 5: // ---------- OVEN HALT --------------
      {
        state = 1;
        lockOven();
        beep();
        break;
      }
      default:
        Serial.println("Invalid FSM state (short press).");
        break;
    }
  }

  /* ----- Handle encoder button long press ----- */
  if (encButton.longPress()) {
    Serial.println("Long press.");
    switch(state)
    {
      case 0: // ---------- SET TIME -------------
      {
        if (edit_time_state == 1) { edit_time_state = 0; }
        else if (edit_time_state == 0) { state = 1; }
        beep();
        break;
      }
      case 1: // ---------- DISPLAY TIME ----------
      {
        // TODO: TEST LOCK UNLOCK
        if (locked) {
          alertShort();
          unlockOven();
        } else {
          alertShort();
          lockOven();
        }
        break;
      }
      case 2: // ---------- SET TIMER SCREEN ----------
      {
        if (edit_time_state == 1) { edit_time_state = 0; }
        else { state = 1; }
        beep();
        break;
      }
      case 3: // ---------- TIMER COUNTDOWN ----------
      {
        state = 5;
        beep();
        break;
      }
      case 4: // ---------- SETTINGS MENU ----------
      {
        if (setting_i == 3 && edit_setting) {
          factoryReset();
          break;
        }
        state = 1;
        beep();
        break;
      }
      case 5: // ---------- OVEN HALT --------------
      {
        state = 1;
        lockOven();
        beep();
        break;
      }
      default:
        Serial.println("Invalid FSM state (long press).");
        break;
    }
  }

  /* ----- Handle encoder button double press ----- */
  if (encButton.doubleClick() && state == 1) {
    if (!locked) {
      Serial.println("Double press.");
      beep();
      edit_setting = false;
      state = 4;
    } else {
      beepError();
      showLockscreen();
    }
  }
}

uint32_t getTimeSec(byte hour, byte minute, byte second) {  
  return (uint32_t)hour * 3600 + (uint32_t)minute * 60 + (uint32_t)second;
}

bool timePassed(uint32_t now, uint32_t target) {
  return ((now + 86400UL - target) % 86400UL) < 1;
}

void settingLabel(int setting) {
  switch(setting_i)
  {
    case 0:
    {
      lc.setChar(0, 0, 'b', false);
      lc.setLed(0, 1, 3, true);
      lc.setLed(0, 1, 5, true);
      lc.setLed(0, 1, 6, true);
      break;
    }
    case 1:
    {
      lc.setChar(0, 0, 'e', false);
      lc.setChar(0, 1, 'c', false);
      lc.setChar(0, 2, 'o', false);
      break;
    }
    case 2:
    {
      lc.setChar(0, 0, 'b', false);
      lc.setChar(0, 1, 'e', false);
      lc.setChar(0, 2, 'p', false);
      break;
    }
    case 3:
    {
      lc.setChar(0, 0, 'f', false);
      lc.setChar(0, 1, 'a', false);
      lc.setChar(0, 2, 'c', false);
      lc.setLed(0, 3, 4, true);
      lc.setLed(0, 3, 5, true);
      lc.setLed(0, 3, 6, true);
      lc.setLed(0, 3, 7, true);
      break;
    }
    default:
      break;
  }
}

void settingValue(int setting) {
  switch(setting_i)
  {
    case 0:
    {
      if (brightness > 9) {
        lc.setDigit(0, 2, brightness/10, false);
      }
      lc.setDigit(0, 3, brightness%10, false);
      break;
    }
    case 1:
    {
      if (eco_mode) {
        lc.setDigit(0, 3, 1, false);
        break;
      }
      lc.setDigit(0, 3, 0, false);
      break;
    }
    case 2:
    {
      if (silent_mode) {
        lc.setDigit(0, 3, 0, false);
        break;
      }
      lc.setDigit(0, 3, 1, false);
      break;
    }
    case 3:
    {
      lc.setLed(0, 0, 0, true);
      lc.setLed(0, 2, 0, true);
      break;
    }
    default:
      break;
  }
}

void beep() {
  if (silent_mode) { return; }
  tone(buzzerPin, 3750, 25);
}

void doubleBeep() {
  if (silent_mode) { return; }
  tone(buzzerPin, 3750, 25);
  delay(100);
  tone(buzzerPin, 3750, 25);
}

void beepError() {
  tone(buzzerPin, 150, 150);
}

void alertShort() {
  tone(buzzerPin, 4000, 500);
}

void alertLong() {
  tone(buzzerPin, 4000, 3000);
}

void lockOven() {
  locked = true;
  state = 1;
  lc.clearDisplay(0);
  lc.setDigit(0, 1, 0, false);
  delay(100);
  lc.setLed(0, 1, 0, true);
  lc.setLed(0, 3, 0, true);
  delay(100);
  lc.setLed(0, 2, 7, true);
  delay(100);
  lc.setLed(0, 3, 7, true);
  delay(100);
  lc.setLed(0, 3, 3, true);
  lc.setLed(0, 3, 5, true);
  delay(1000);
}

void unlockOven() {
  locked = false;
  ovenUnlockMillis = millis();
  showLockscreen();
  delay(100);
  lc.setLed(0, 3, 3, false);
  lc.setLed(0, 3, 5, false);
  delay(100);
  lc.setLed(0, 3, 7, false);
  delay(100);
  lc.setLed(0, 2, 7, false);
  delay(100);
  lc.setLed(0, 3, 0, false);
  lc.setDigit(0, 1, 0, false);
  delay(100);
  lc.clearDisplay(0);
  delay(250);
}
 
void showLockscreen() {
  lc.clearDisplay(0);
  lc.setDigit(0, 1, 0, true);
  lc.setLed(0, 3, 0, true);
  lc.setLed(0, 2, 7, true);
  lc.setLed(0, 3, 7, true);
  lc.setLed(0, 3, 3, true);
  lc.setLed(0, 3, 5, true);
  delay(1000);
}

void factoryReset() {
  EEPROM.write(E_INIT, 'F');
  wdt_disable();
  wdt_enable(WDTO_2S);
  delay(5000);
}

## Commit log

2026-03-22 Initial commit.
    [BOM_Board1_PCB1_2025-12-14.csv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]
2026-03-23 Added encoder knob and reset button parts 3D models.
    [knob_adapter_v4.3mf, knob_cap_v4.3mf, rst_button.3mf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]
